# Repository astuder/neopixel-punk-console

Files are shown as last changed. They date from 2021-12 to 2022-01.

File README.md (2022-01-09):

# NeoPixel Punk Console

The goal of this project is to display colorful patterns on a strip of WS2812 or SK6812 RGB LEDs (aka NeoPixels) without the help of an MCU.

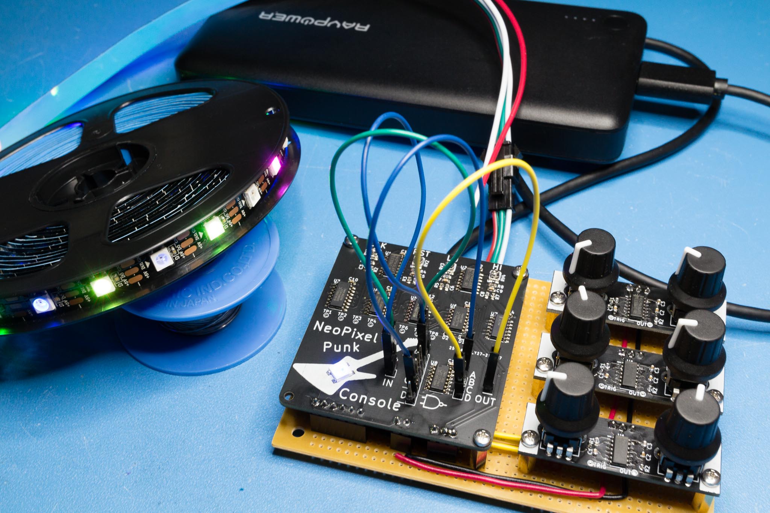
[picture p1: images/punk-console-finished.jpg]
assembled project


This repository contains the design files for the hardware.
* [punk-console-main](neopixel-punk-main): RGB LED driver circuit
* [punk-console-oscillator](neopixel-punk-oscillator): Pattern generator circuit

Both folders contain a PDF of the schematic and the EDA project created with [KiCad](https://www.kicad.org/) version 6.0.

A detailed discussion of the design is published [here](https://hackaday.io/project/183093-neopixel-punk-console).

Featured on [Hackaday](https://hackaday.com/2022/01/01/neopixel-punk-console-drives-ws2812s-using-555-timers/)

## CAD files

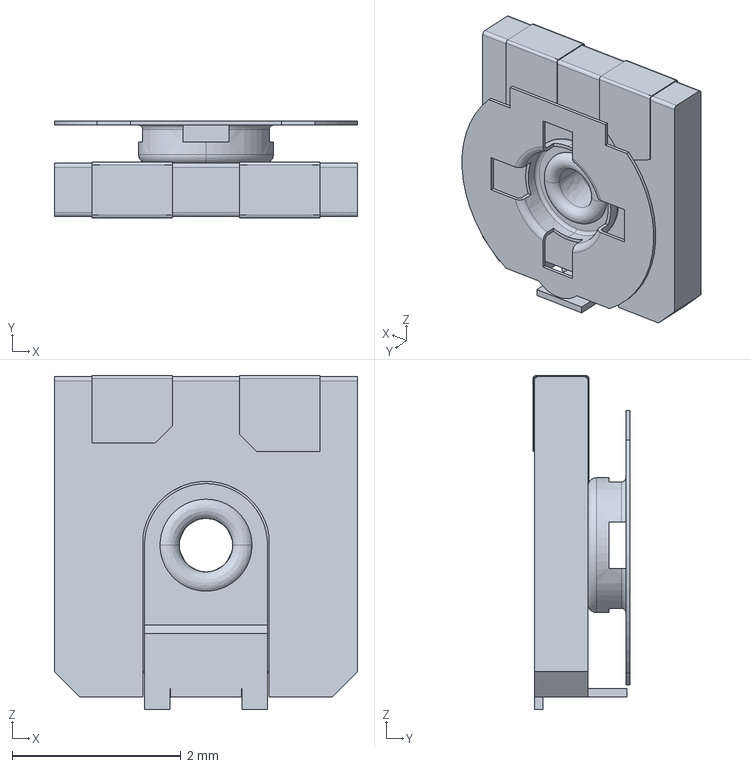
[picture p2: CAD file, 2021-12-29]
neopixel-punk-main/3d/TC-33X-2.stp
3.60 x 1.15 x 3.96 mm

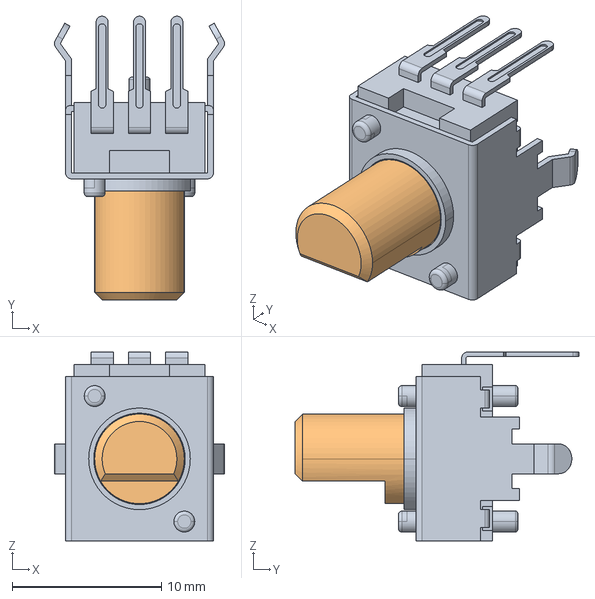
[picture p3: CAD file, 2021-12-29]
neopixel-punk-oscillator/3d/ptv09a-4x15f-xxxx.stp
11.4 x 19.0 x 12.7 mm

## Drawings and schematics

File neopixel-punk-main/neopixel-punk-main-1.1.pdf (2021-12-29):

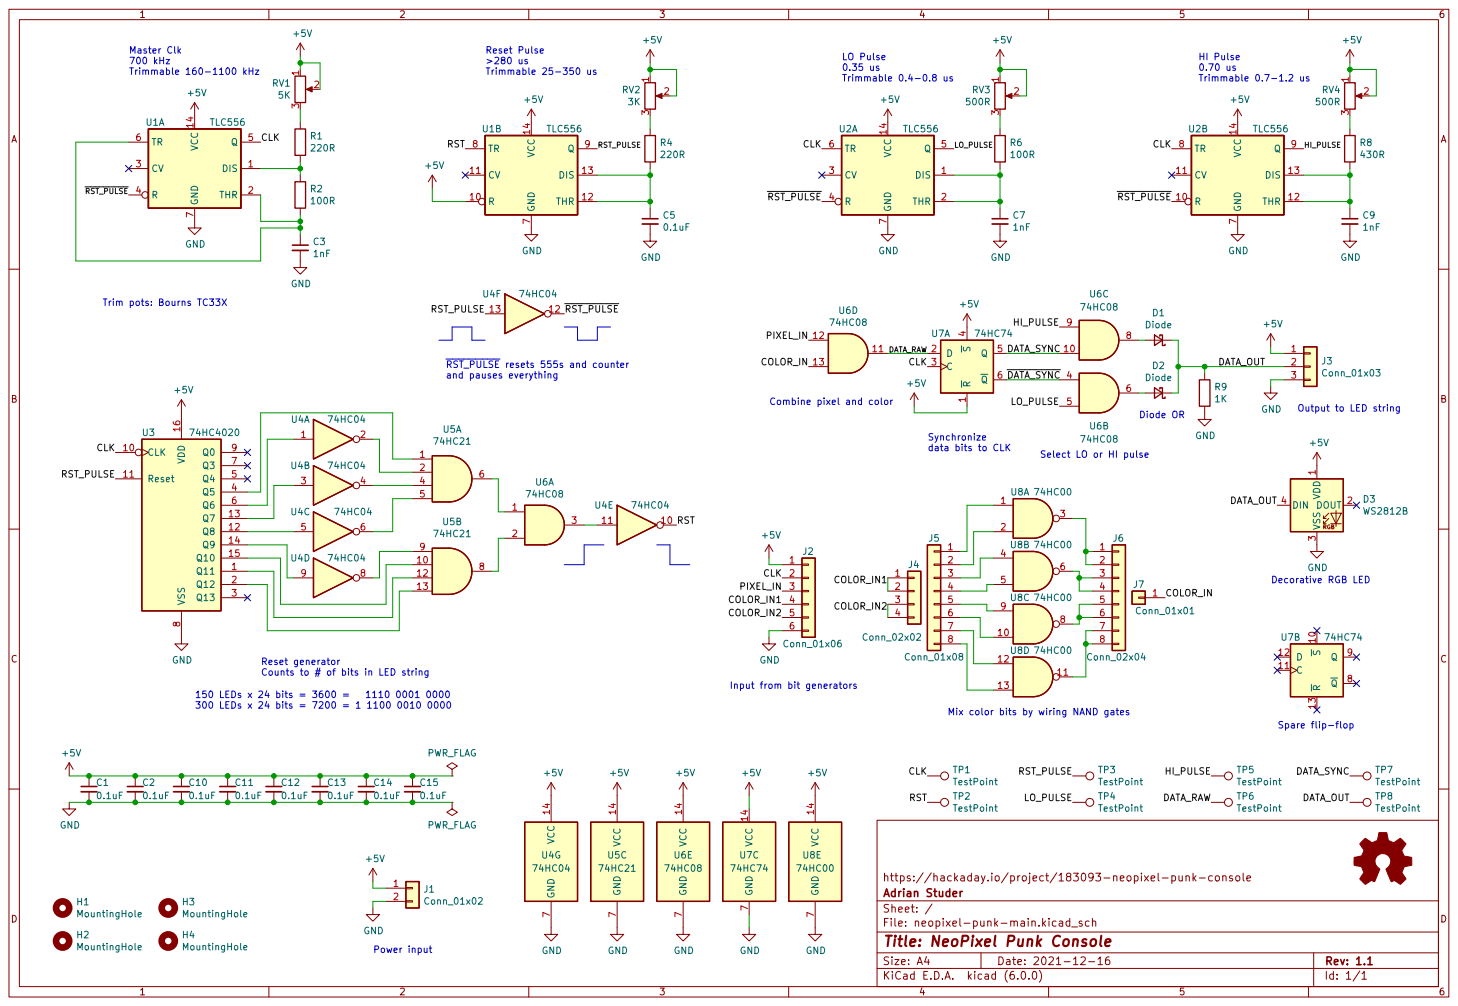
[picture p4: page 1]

and pauses everything Reset Pulse >280 us Trimmable 25-350 us Rev 1.1: - add 1K pull-down R9 on DATA_OUT

0.70 us Trimmable 0.7-1.2 us Trim pots: Bourns TC33X

Combine pixel and color

Output to LED string

Select LO or HI pulse

Reset generator
Counts to # of bits in LED string
H1MountingHole +5V

Input from bit generators

Mix color bits by wiring NAND gates

File: neopixel-punk-main.kicad_sch Sheet: / Adrian Studer https://hackaday.io/project/183093-neopixel-punk-console

Id: 1/1 Title: NeoPixel Punk Console

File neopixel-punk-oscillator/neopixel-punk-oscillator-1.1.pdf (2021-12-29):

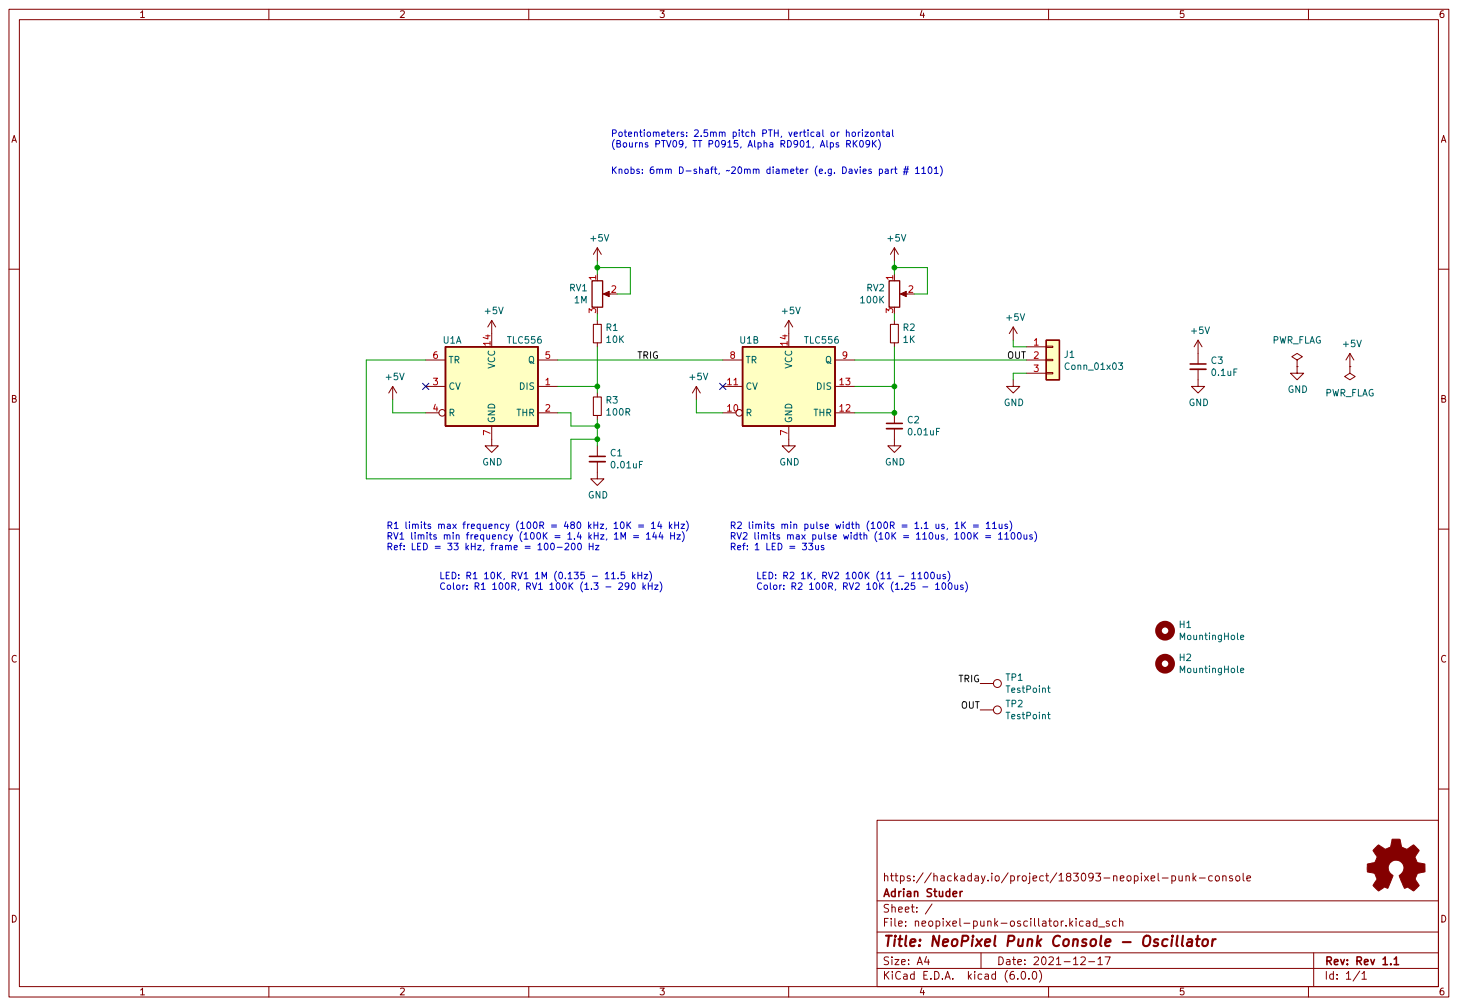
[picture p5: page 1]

Potentiometers: 2.5mm pitch PTH, vertical or horizontal
(Bourns PTV09, TT P0915, Alpha RD901, Alps RK09K)

Knobs: 6mm D-shaft, ~20mm diameter (e.g. Davies part # 1101)

R1 limits max frequency (100R = 480 kHz, 10K = 14 kHz)
RV1 limits min frequency (100K = 1.4 kHz, 1M = 144 Hz) Ref: LED = 33 kHz, frame = 100-200 Hz LED: R1 10K, RV1 1M (0.135 - 11.5 kHz)

R2 limits min pulse width (100R = 1.1 us, 1K = 11us)
RV2 limits max pulse width (10K = 110us, 100K = 1100us) Ref: 1 LED = 33us LED: R2 1K, RV2 100K (11 - 1100us)

File: neopixel-punk-oscillator.kicad_sch Sheet: / Adrian Studer https://hackaday.io/project/183093-neopixel-punk-console

Id: 1/1 Title: NeoPixel Punk Console - Oscillator

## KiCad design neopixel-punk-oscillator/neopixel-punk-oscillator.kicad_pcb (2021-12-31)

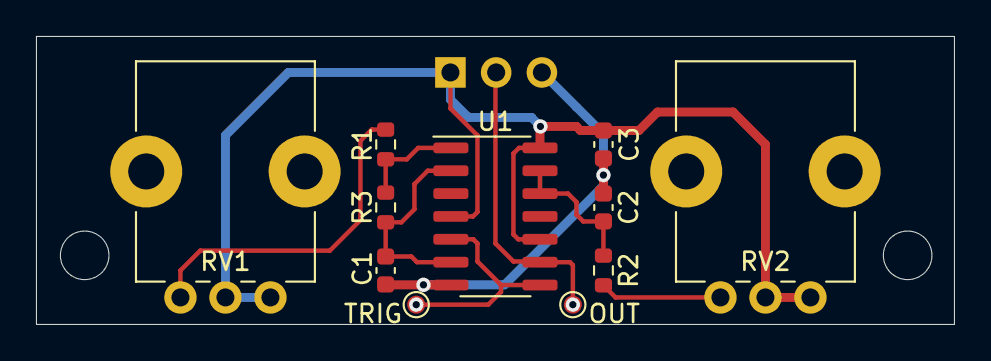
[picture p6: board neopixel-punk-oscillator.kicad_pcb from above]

Board: 2 copper layers, 51.0 x 16.0 mm, 14 parts (1 on the bottom side), 9 nets.

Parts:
C1, C2: 0.01uF; C_0603_1608Metric
C3: 0.1uF; C_0603_1608Metric
H1, H2: MountingHole; MountingHole_2.7mm_M2.5
J1: Conn_01x03; PinHeader_1x03_P2.54mm_Vertical
R1: 1K; R_0603_1608Metric
R2, R3: 100R; R_0603_1608Metric
RV1: 1M; Potentiometer_Bourns_PTV09A-1_Single_Vertical
RV2: 10K; Potentiometer_Bourns_PTV09A-1_Single_Vertical
TP1, TP2: TestPoint; TestPoint_Pad_D1.0mm
U1: TLC556; SOIC-14_3.9x8.7mm_P1.27mm

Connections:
+5V: C3.1, J1.1, RV1.1, RV1.2, RV2.1, RV2.2, U1.4, U1.10, U1.14
/OUT: J1.2, TP2.1, U1.9
/TRIG: TP1.1, U1.5, U1.8
GND: C1.2, C2.2, C3.2, J1.3, U1.7
unnamed: C1.1, R3.2, U1.2, U1.6
unnamed: C2.1, R2.2, U1.12, U1.13
unnamed: R1.1, RV1.3
unnamed: R1.2, R3.1, U1.1
unnamed: R2.1, RV2.3

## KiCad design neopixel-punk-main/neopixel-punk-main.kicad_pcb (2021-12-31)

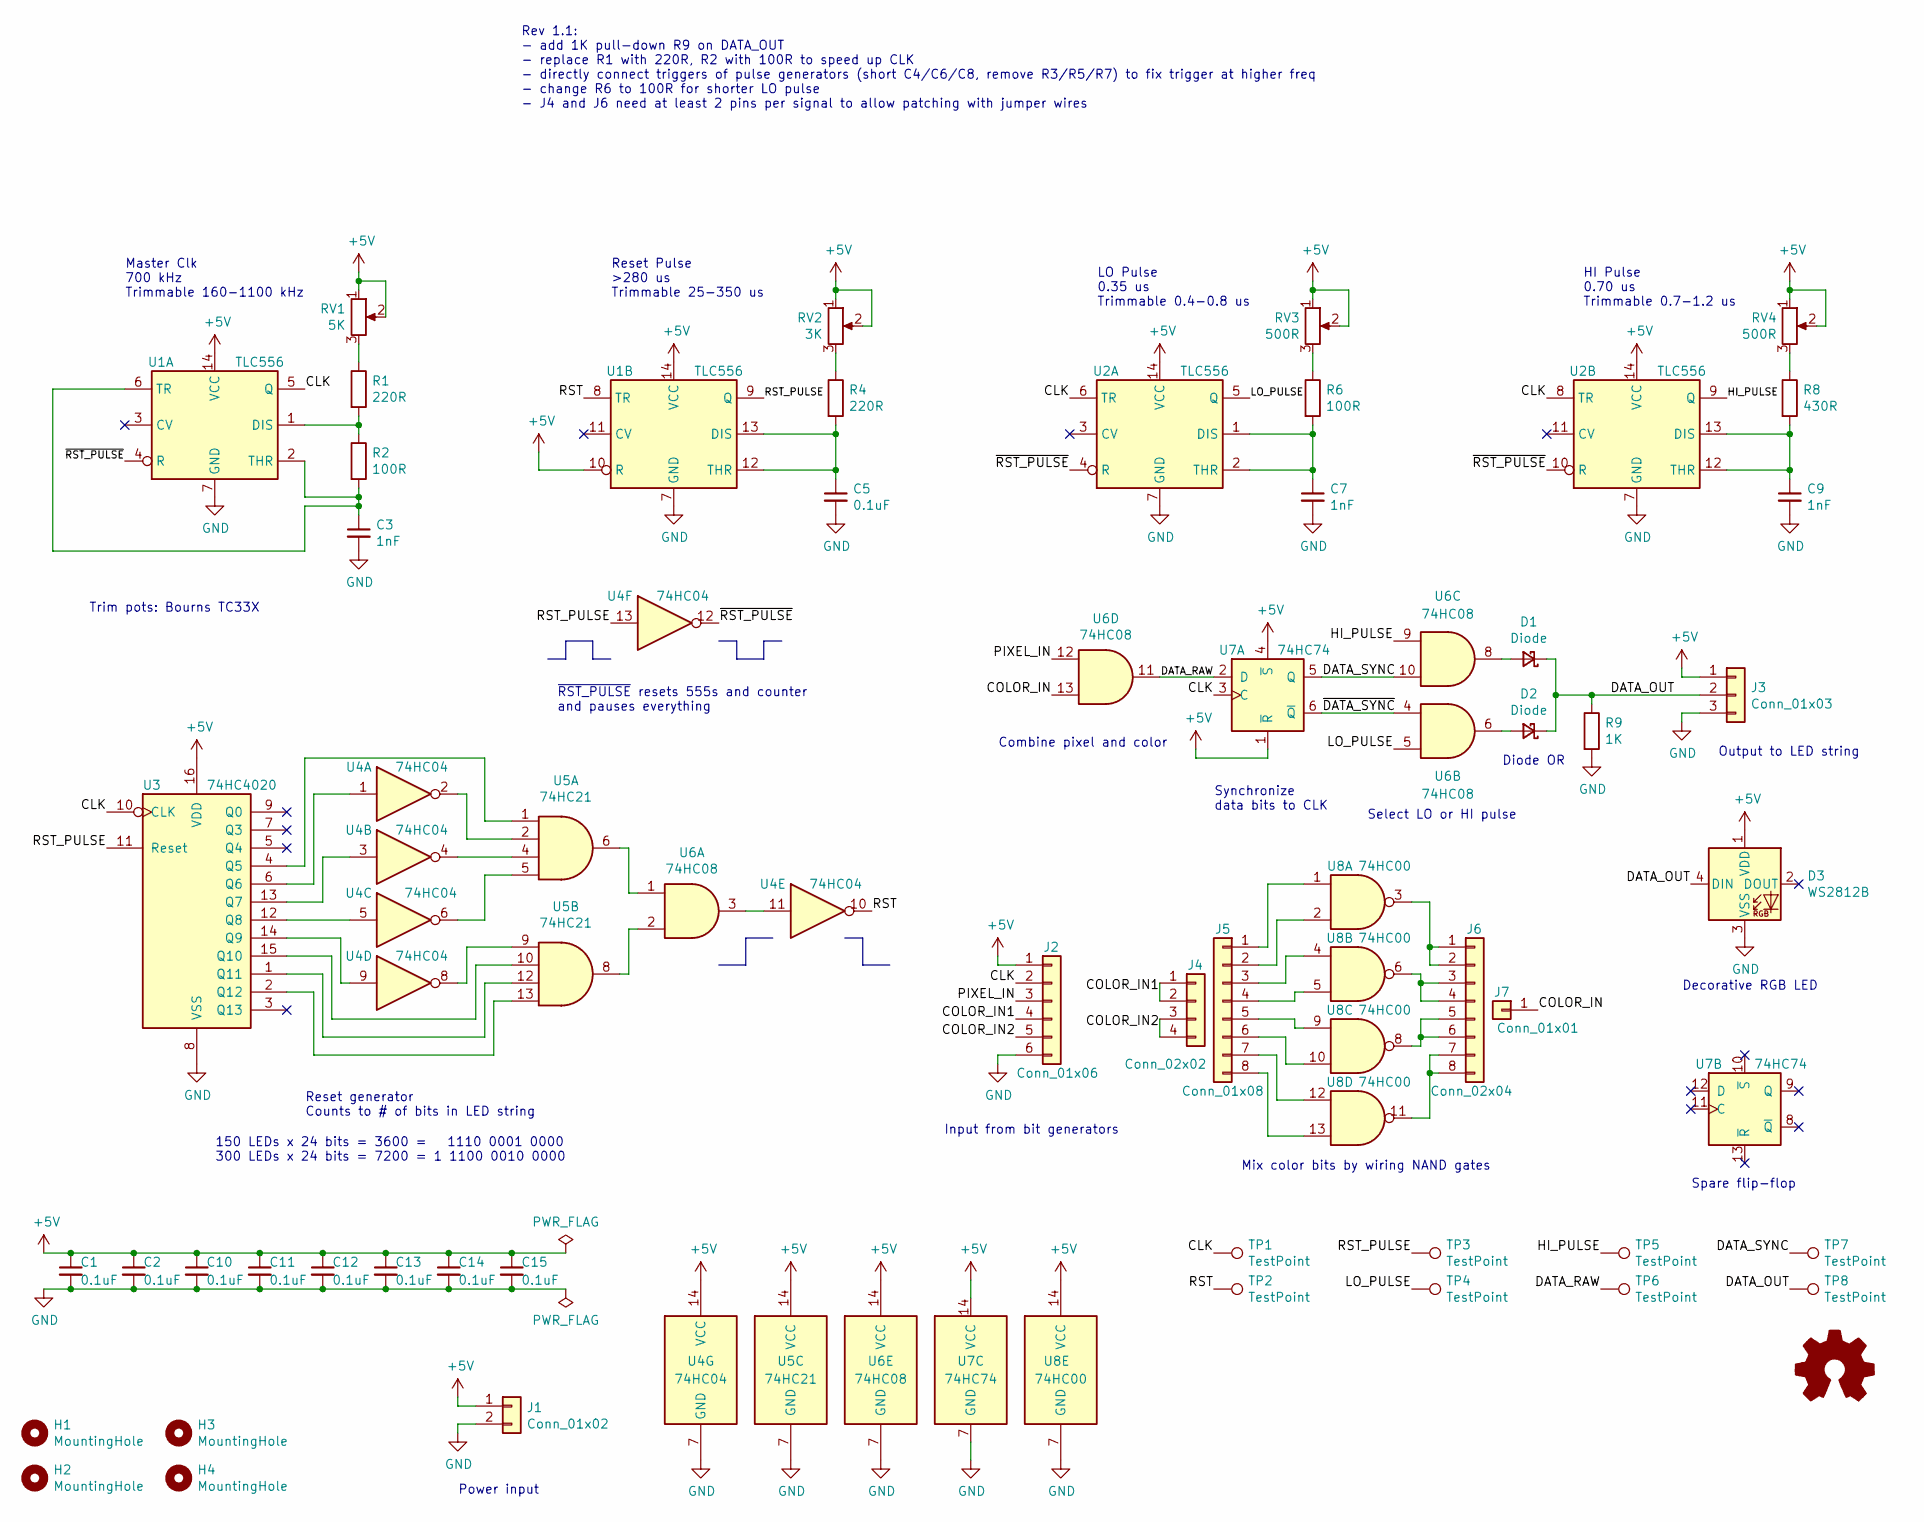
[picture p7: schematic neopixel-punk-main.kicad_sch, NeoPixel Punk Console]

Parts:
C1, C2, C5, C10, C11, C12, C13, C14, C15: 0.1uF; C_0603_1608Metric
C3, C7, C9: 1nF; C_0603_1608Metric
D1, D2: Diode; D_SOD-523
D3: WS2812B; LED_WS2812B_PLCC4_5.0x5.0mm_P3.2mm
H1, H2, H3, H4: MountingHole; MountingHole_2.7mm_M2.5
J1: Conn_01x02; PinHeader_1x02_P2.54mm_Vertical
J2: Conn_01x06; PinHeader_2x02_P2.54mm_Vertical
J3: Conn_01x03; PinHeader_1x03_P2.54mm_Vertical
J4: Conn_02x02; PinHeader_1x02_P2.54mm_Vertical
J5: Conn_01x08; PinHeader_1x08_P2.54mm_Vertical
J6: Conn_02x04; PinHeader_2x04_P2.54mm_Vertical
J7: Conn_01x01; PinHeader_1x01_P2.54mm_Vertical
R1, R4: 220R; R_0603_1608Metric
R2, R6: 100R; R_0603_1608Metric
R8: 430R; R_0603_1608Metric
R9: 1K; R_0603_1608Metric
RV1: 5K; Potentiometer_Bourns_TC33X_Vertical
RV2: 3K; Potentiometer_Bourns_TC33X_Vertical
RV3, RV4: 500R; Potentiometer_Bourns_TC33X_Vertical
TP1, TP2, TP3, TP4, TP5, TP6, TP7, TP8: TestPoint; TestPoint_Pad_D1.0mm
U1, U2: TLC556; SOIC-14_3.9x8.7mm_P1.27mm
U3: 74HC4020; SOIC-16_3.9x9.9mm_P1.27mm
U4: 74HC04; SOIC-14_3.9x8.7mm_P1.27mm
U5: 74HC21; SOIC-14_3.9x8.7mm_P1.27mm
U6: 74HC08; SOIC-14_3.9x8.7mm_P1.27mm
U7: 74HC74; SOIC-14_3.9x8.7mm_P1.27mm
U8: 74HC00; SOIC-14_3.9x8.7mm_P1.27mm

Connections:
+5V: C1.1, C2.1, C10.1, C11.1, C12.1, C13.1, C14.1, C15.1, D3.1 (VDD), J1.1, J2.1, J3.1, RV1.1, RV1.2, RV2.1, RV2.2, RV3.1, RV3.2, RV4.1, RV4.2, U1.10 (R), U1.14 (VCC), U2.14 (VCC), U3.16 (VDD), U4.14 (VCC), U5.14 (VCC), U6.14 (VCC), U7.1 (~R), U7.4 (~S), U7.14 (VCC), U8.14 (VCC)
/CLK: J2.2, TP1.1, U1.5 (Q), U2.6 (TR), U2.8 (TR), U3.10 (CLK), U7.3 (C)
/COLOR_IN: J7.1, U6.13
/COLOR_IN1: J2.4, J4.1, J4.2
/COLOR_IN2: J2.5, J4.3, J4.4
/DATA_OUT: D1.1 (K), D2.1 (K), D3.4 (DIN), J3.2, R9.1, TP8.1
/DATA_RAW: TP6.1, U6.11, U7.2 (D)
/DATA_SYNC: TP7.1, U6.10, U7.5 (Q)
/HI_PULSE: TP5.1, U2.9 (Q), U6.9
/LO_PULSE: TP4.1, U2.5 (Q), U6.5
/PIXEL_IN: J2.3, U6.12
/RST: TP2.1, U1.8 (TR), U4.10
/RST_PULSE: TP3.1, U1.9 (Q), U3.11 (Reset), U4.13
/~DATA_SYNC: U6.4, U7.6 (~Q)
/~RST_PULSE: U1.4 (R), U2.4 (R), U2.10 (R), U4.12
GND: C1.2, C2.2, C3.2, C5.2, C7.2, C9.2, C10.2, C11.2, C12.2, C13.2, C14.2, C15.2, D3.3 (VSS), J1.2, J2.6, J3.3, R9.2, U1.7 (GND), U2.7 (GND), U3.8 (VSS), U4.7 (GND), U5.7 (GND), U6.7 (GND), U7.7 (GND), U8.7 (GND)
unnamed: C3.1, R2.2, U1.2 (THR), U1.6 (TR)
unnamed: C5.1, R4.2, U1.12 (THR), U1.13 (DIS)
unnamed: C7.1, R6.2, U2.1 (DIS), U2.2 (THR)
unnamed: C9.1, R8.2, U2.12 (THR), U2.13 (DIS)
unnamed: D1.2 (A), U6.8
unnamed: D2.2 (A), U6.6
unnamed: J5.1, U8.1
unnamed: J5.2, U8.2
unnamed: J5.3, U8.4
unnamed: J5.4, U8.5
unnamed: J5.5, U8.9
unnamed: J5.6, U8.10
unnamed: J5.7, U8.12
unnamed: J5.8, U8.13
unnamed: J6.1, J6.2, U8.3
unnamed: J6.3, J6.4, U8.6
unnamed: J6.5, J6.6, U8.8
unnamed: J6.7, J6.8, U8.11
unnamed: R1.1, RV1.3
unnamed: R1.2, R2.1, U1.1 (DIS)
unnamed: R4.1, RV2.3
unnamed: R6.1, RV3.3
unnamed: R8.1, RV4.3
unnamed: U3.1 (Q11), U5.12
unnamed: U3.2 (Q12), U5.13
unnamed: U3.4 (Q5), U5.1
unnamed: U3.6 (Q6), U4.1
unnamed: U3.12 (Q8), U4.5
unnamed: U3.13 (Q7), U4.3
unnamed: U3.14 (Q9), U4.9
unnamed: U3.15 (Q10), U5.10
unnamed: U4.2, U5.2
unnamed: U4.4, U5.4
unnamed: U4.6, U5.5
unnamed: U4.8, U5.9
unnamed: U4.11, U6.3
unnamed: U5.6, U6.1
unnamed: U5.8, U6.2

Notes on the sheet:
Reset generator Counts to # of bits in LED string
Synchronize data bits to CLK
Master Clk 700 kHz Trimmable 160-1100 kHz
Output to LED string
Decorative RGB LED
Select LO or HI pulse
HI Pulse 0.70 us Trimmable 0.7-1.2 us
Reset Pulse >280 us Trimmable 25-350 us
Combine pixel and color
Power input
Trim pots: Bourns TC33X
Mix color bits by wiring NAND gates
Input from bit generators
~{RST_PULSE} resets 555s and counter and pauses everything
Spare flip-flop
150 LEDs x 24 bits = 3600 = 1110 0001 0000 300 LEDs x 24 bits = 7200 = 1 1100 0010 0000
Rev 1.1: - add 1K pull-down R9 on DATA_OUT - replace R1 with 220R, R2 with 100R to speed up CLK - directly connect triggers of pulse generators (short C4/C6/C8, remove R3/R5/R7) to fix trigger at higher freq - change R6 to 100R for shorter LO pulse - J4 and J6 need at least 2 pins per signal to all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
LO Pulse 0.35 us Trimmable 0.4-0.8 us
Diode OR

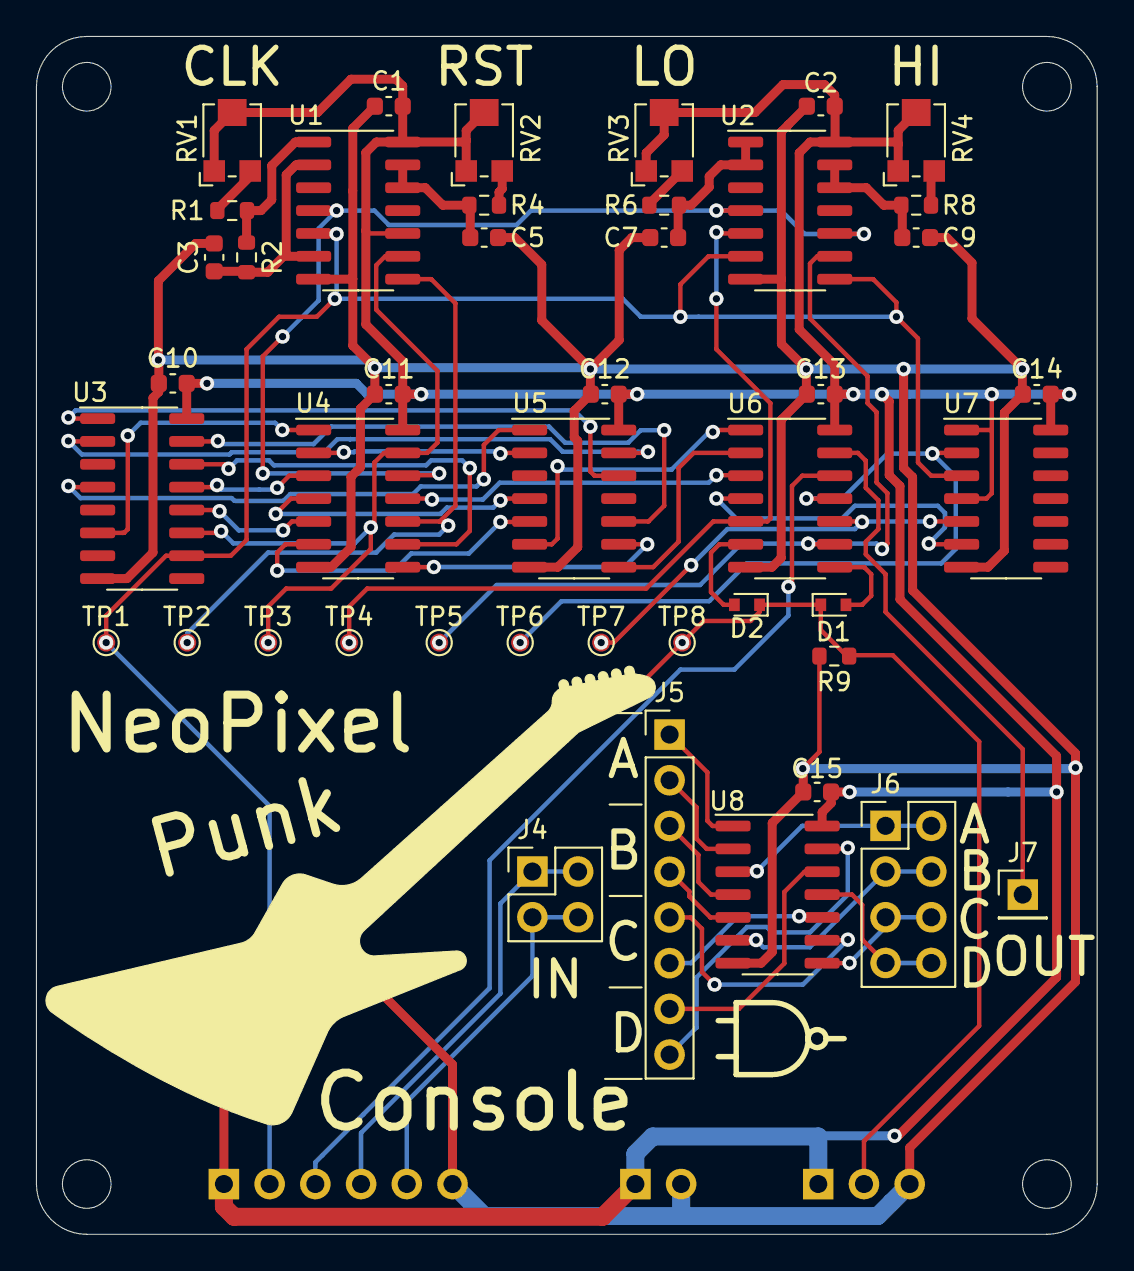
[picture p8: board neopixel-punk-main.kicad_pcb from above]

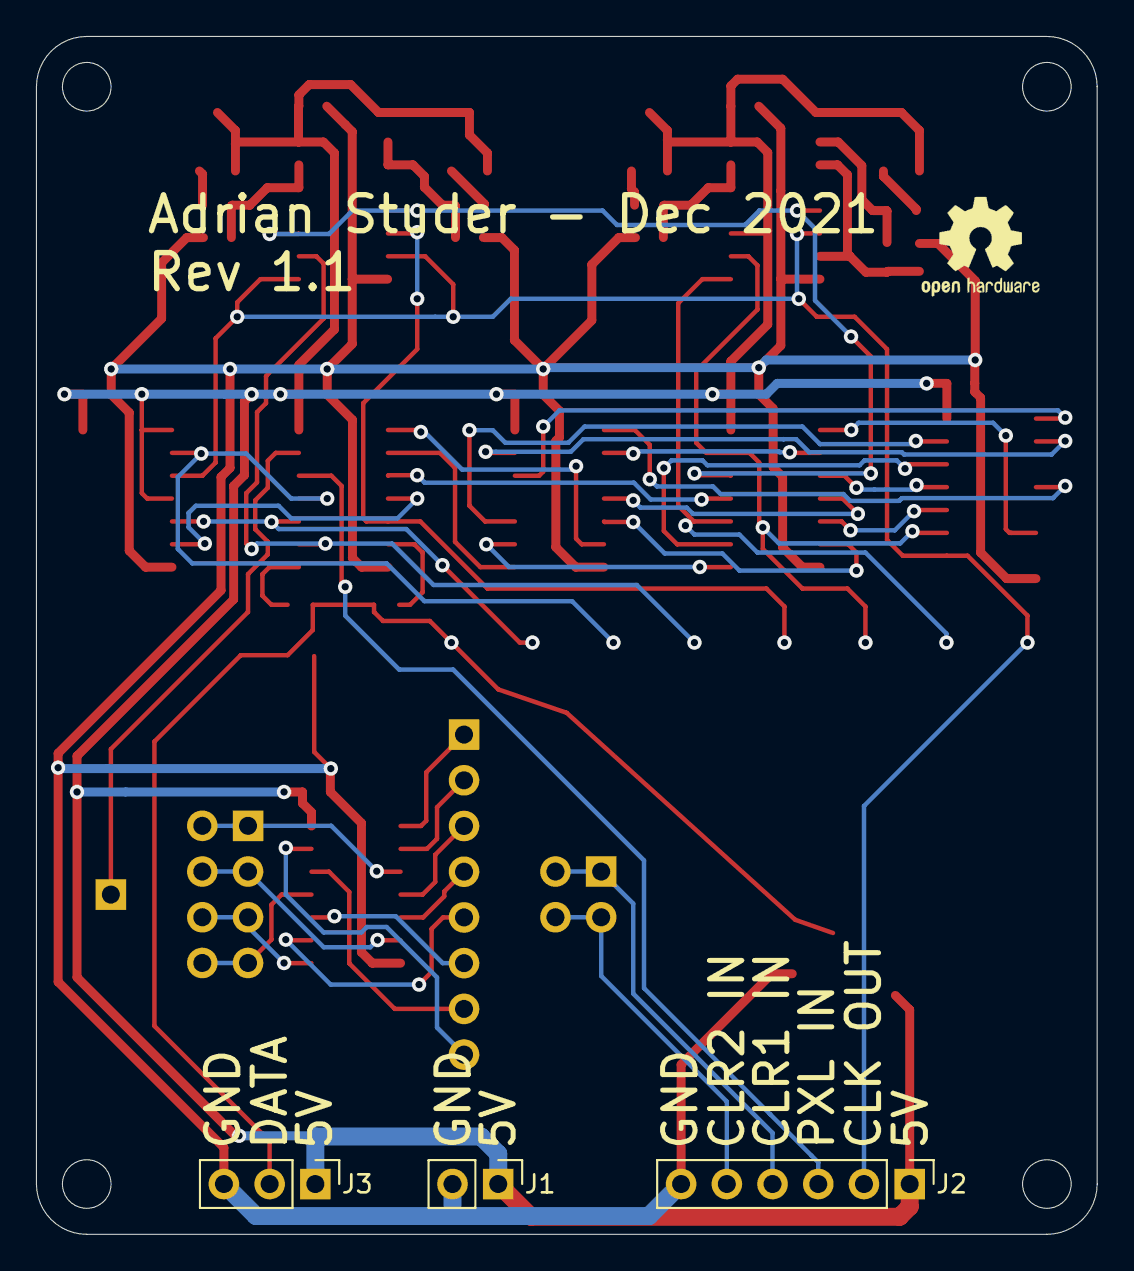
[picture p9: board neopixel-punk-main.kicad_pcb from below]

Board: 2 copper layers, 58.9 x 66.5 mm, 52 parts (3 on the bottom side), 54 nets.

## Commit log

2021-12-29 hw version 1.1
    [TC-33X-2.stp, neopixel-punk-main.kicad_pcb, neopixel-punk-main.kicad_sch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]
2021-12-31 black PCB color
    [neopixel-punk-main.kicad_pcb, neopixel-punk-oscillator.kicad_pcb]
